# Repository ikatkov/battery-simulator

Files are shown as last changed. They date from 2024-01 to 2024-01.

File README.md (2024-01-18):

# Electronic battery simulator (also works as 35W electronic load)

## Description

Useful for testing battery chargers. 
Designed to use from single lithium batteries to 5S packs i.e. from 3.7V to 18V. Max charging current 2.3A 

Set the "battery" voltage with coarse/fine voltage pots, connect the charger and start the charging process. 
Adjust the "battery" voltage up/down to test how the charger responds. Set max allowed "charge" current with the current pot.

This device simulates battery discharging, current is limited by 200 Ohm resistors i.e. 60-120mA. When in "discharge" mode the
green LED is lit.
When the device simulates battery charging - the current is limited by both the internal charger circuitry and max allowed "charge" current. 
The absolute max is ~2.3A When in "charge" mode the red LED is lit.

A note on `*S` packs:
A typical pack charger senses the voltage across each battery in the pack. This is not implemented inside
but can be built as a pluggable add-on. One side plugs into the banana input of this electronic battery simulator, and the other side forms multiple voltage dividers, as many as the charger wants. Example

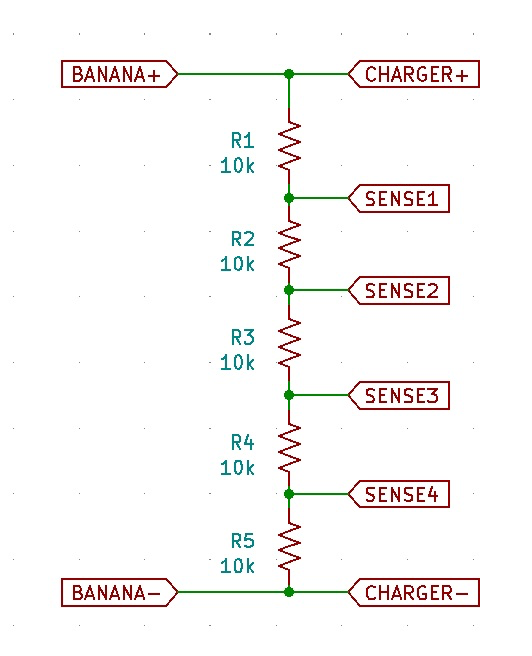
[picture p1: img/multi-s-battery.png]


### Input voltage
Input voltage (VCC): 12-24V. The max "battery" voltage one can set is ~3V below this. 

* LM358 output swing from the top rail is 1.5V
* BJT voltage drop 0.7V
* Diode voltage drop 0.7V

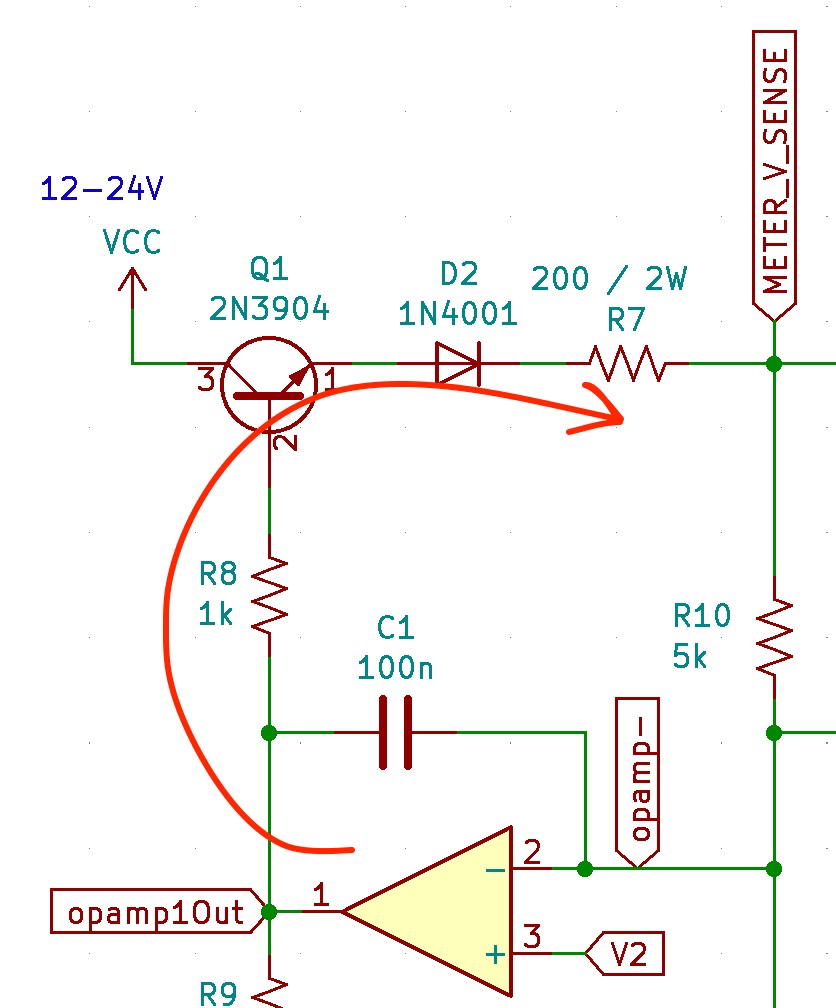
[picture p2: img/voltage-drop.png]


Max voltage available to the cooling fan is ~2.75V below VCC. For the maximum cooling, VCC should be 14V+

* LM358 output swing from the top rail is 1.5V
* LM317 ADJ-to-out is 1.25V

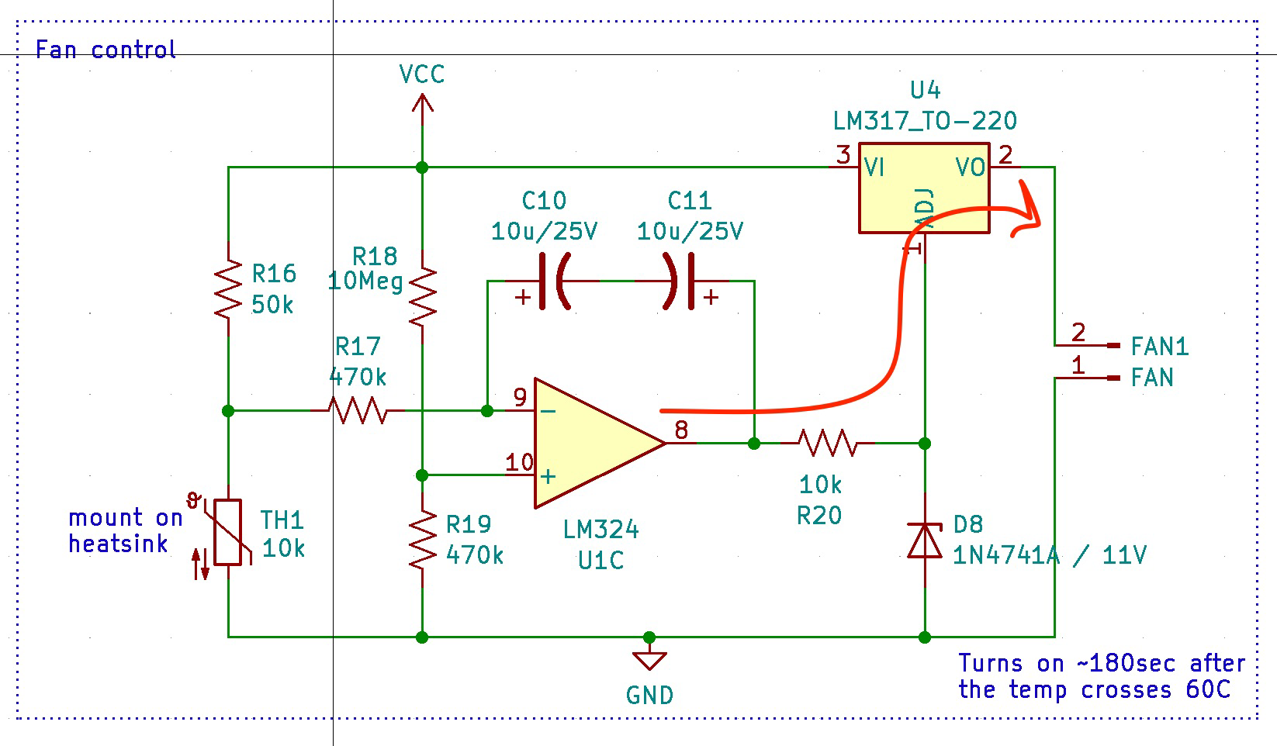
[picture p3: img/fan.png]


### Charger voltage
Charger voltage 0-20V. This is limited by the MOSFET Vds

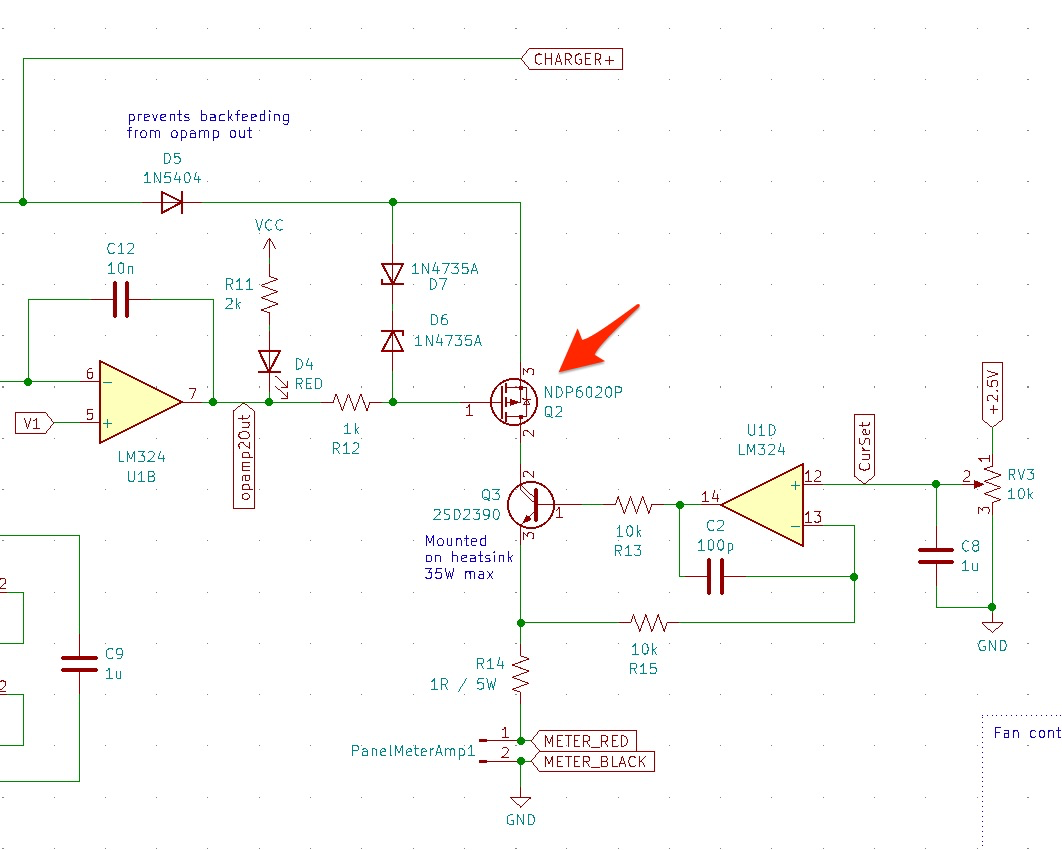
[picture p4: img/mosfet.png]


## Usage

Typical examples:

* manually increase the voltage to 4.2V and expect the lithium battery charger to stop
* manually limit/reduce the max allowed charging current, simulating increased battery resistance, and expect the charger to stop

Non-typical example:

* Set min "battery" voltage, apply external power, and use as a dummy load.

## Limits

Do not exceed 35W continuous heat dissipation. Pass BJT transistor will blow.

Do not exceed 20V charger voltage, switch MOSFET will blow.

Do not exceed 30V input voltage, opamps will blow.

## Fabrication

[LTSpice](ltspice)

[Schematic](schematic.pdf)

[Kicad](kicad)

[Enclosure, knobs](fusion360)

[Notes on fabricating metal enclosures](Metal%20enclosure%20project%20box.md)

Heatsink is not shown on the render below
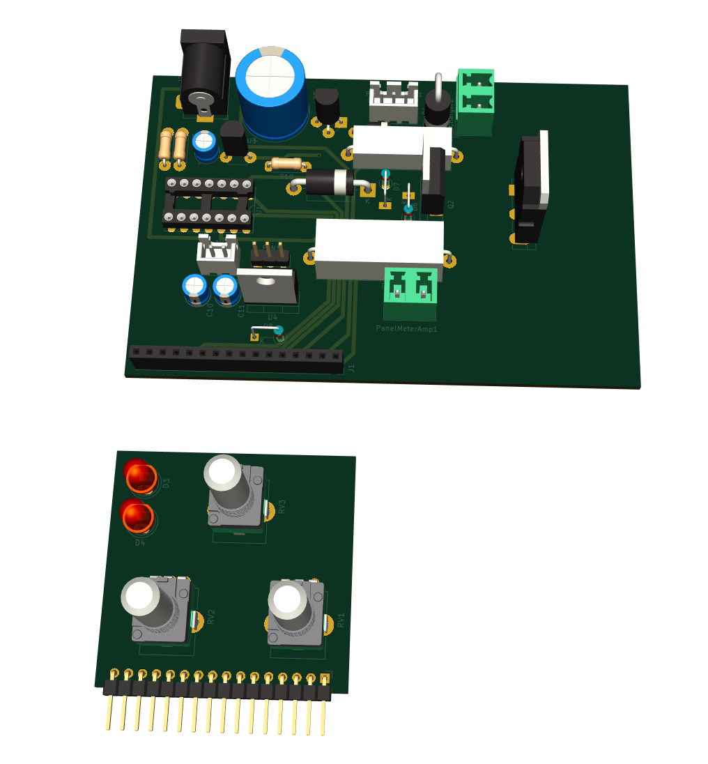
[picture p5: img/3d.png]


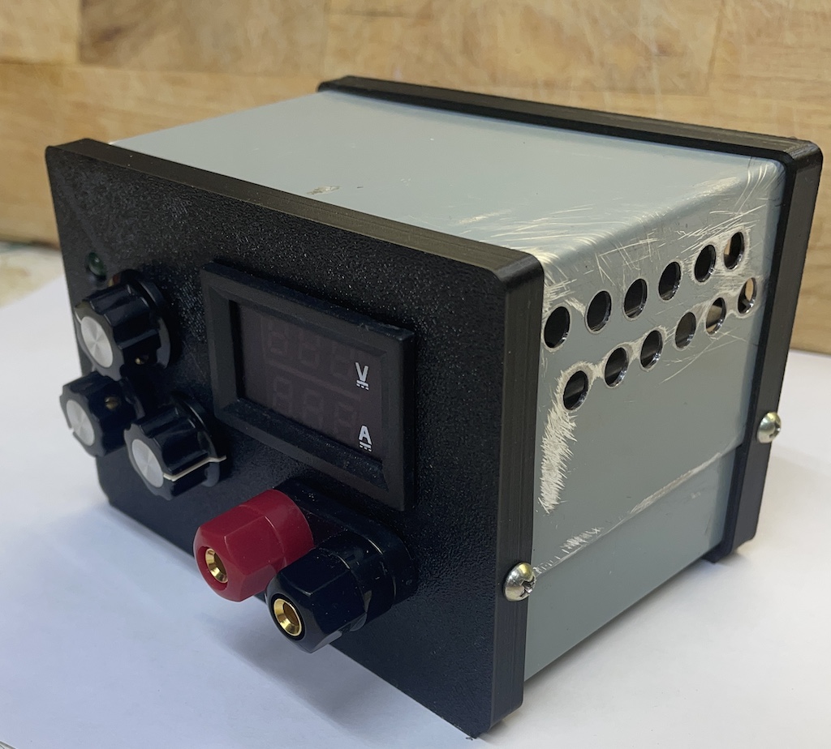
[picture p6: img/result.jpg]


## Notes

The main surprise is that this thing is as usable as a general-purpose dummy load as much as an electronic battery itself.

Do not make daughter boards that have buttons or pots. Mount them separately, and connect them with wires. It is wobbly, the daughter board needs to be secured to a vertical panel, while the vertical panel needs to be removable by design. Total PITA, don't do it again.

Despite PCB being sparsely populated, wires make the inside of the box very very crowded. Need to make the box deeper, +1-2-3 cm depth would not be noticeable but would make wire management easier.

Make the cooling fan blow air on the heat sink along the fins.

This can't be stressed enough - position all connectors, mounting holes and heatsink on the PCB before routing.

See [Notes on fabricating metal enclosures](Metal%20enclosure%20project%20box.md)

For a small enclosure like here, it takes longer to manufacture from metal than to 3D print.

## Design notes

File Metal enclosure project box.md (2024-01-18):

# How to make a project box

1mm thick sheet metal is good enough (rigid enough) for all reasonably sized project boxes.
Harvest from any home appliance that has metal sides. 

Assemble from two metal U-shaped parts. Top and bottom. The top part sides overlap the bottom part sides.
The top and bottom parts are held together by two sheet metal screws on each side.
The front and bottom panels are 3d printed plastic, with all the cutouts. 2mm thickness front, 1.5mm flanges
They overlap metal parts hiding metal cut-off edge imperfections.
Flanges are slotted to hold plastic better

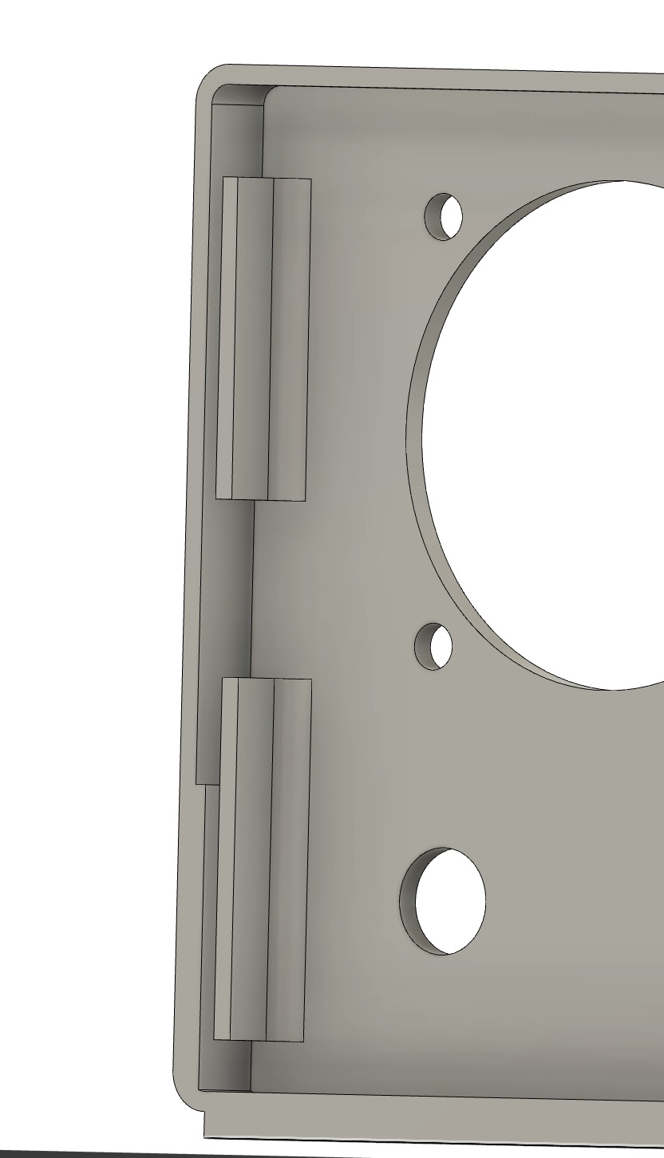
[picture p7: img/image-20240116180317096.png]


Notice how sheet metal parts fit into the gaps. Notice different set-back at the top and bottom due to sheet metal overlap

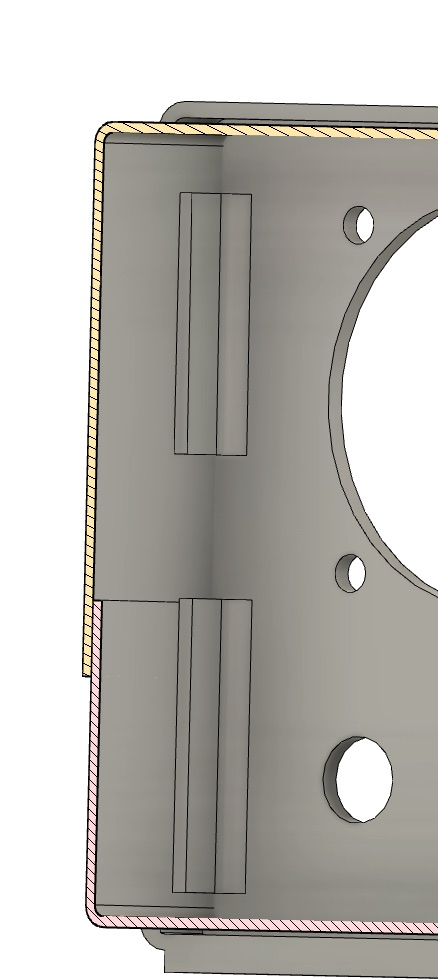
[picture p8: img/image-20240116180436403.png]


Use a sheet metal screw with a pilot hole to hold it together. Drill the hole once the box is fully assembled, right through 
plastic-metal-metal-plastic.

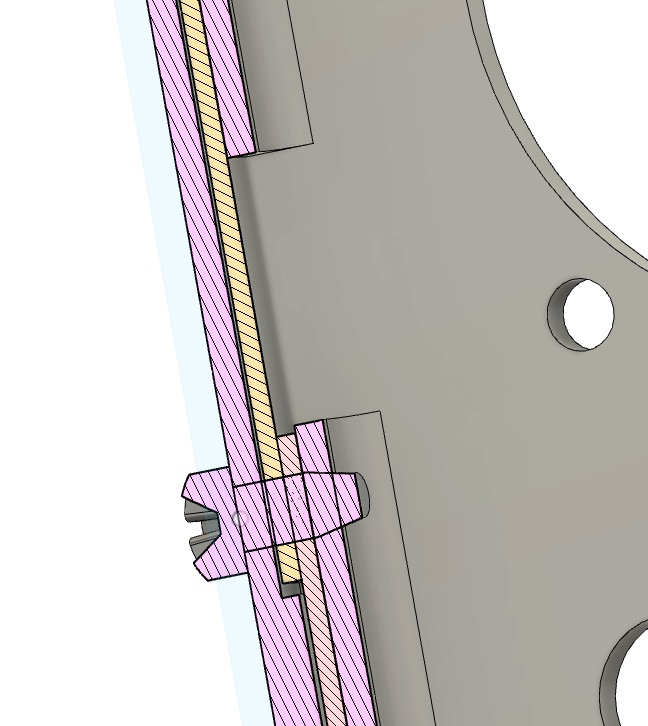
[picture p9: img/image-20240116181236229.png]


# Result



## Metal cutting tips
Align unfolded U-shaped parts together, in one long pattern. So that once it is cut, their width is the same. This width is the depth of the box. 
The best way of cutting a straight line is to score hard and then bend/unbend until the metal breaks.
Handholding power sheers gives OK results. Depends on a steady hand and might be a 1mm deviation at best. Need to try to use a metal plate as a guide. It seems tricky, as the shear nose is round.

## Metal bending tips
When bending, align the bend line with the gap between hand brake plates. Move the top metal plate ~0.2-0.3mm away from the crack. Maybe use these printed dotted lines on the pattern, to know how much to move back?

## PCB mounting tips
Place PCB in the desired location, and mark holes on the bottom metal part with a marker. Drill. 
Expect the result to be off the holes in the PCB. Enlarge PCB holes to align the metal holes with a rotary tool.
Take a 6mm spacer with threads inside, and screw the PCB from the top to it, now PCB has tiny "legs". Use a short screw to leave 50% of the spacer empty on the inside. Use another short screw from the bottom of the box, to mount the whole PCB assembly through these legs. Two machine screws are facing each other.

Do a proper ribbon/wire connection from the main horizontal PCB to panel mounted vertical one, do not do pins and headers - the vertical board becomes wobbly. This is especially bad if the vertical board has potentiometers or buttons.

## PCB layout tips
Set back mounting holes 15mm away from edges, otherwise front/back plastic panel flanges conflict with bolt heads. Expect the holes to be enlarged manually later.
Leave enough space around ~ 10mm diameter restriction zone.

Position heatsinks and fans and ports/connectors before doing any trace routing. Make the fan blow air on them.

## Industry examples

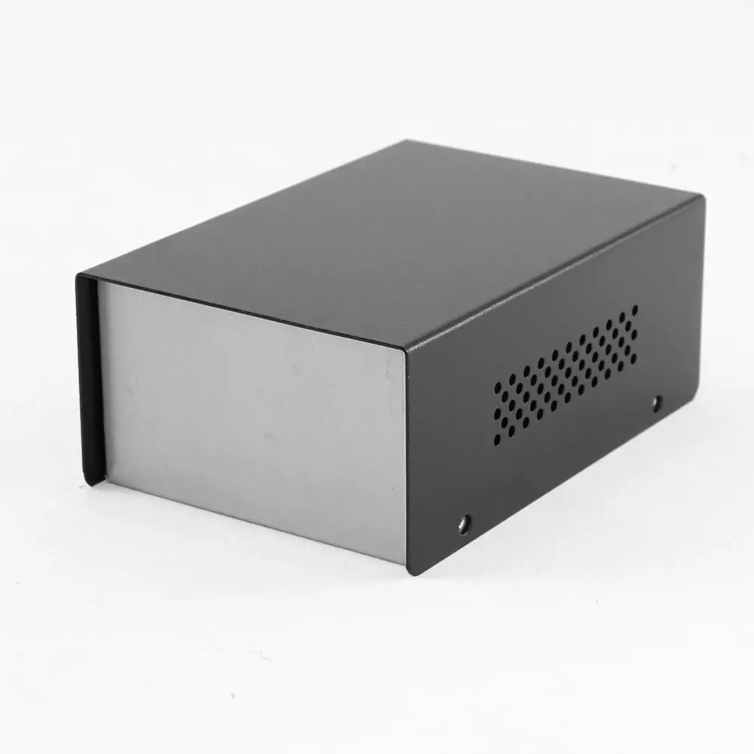
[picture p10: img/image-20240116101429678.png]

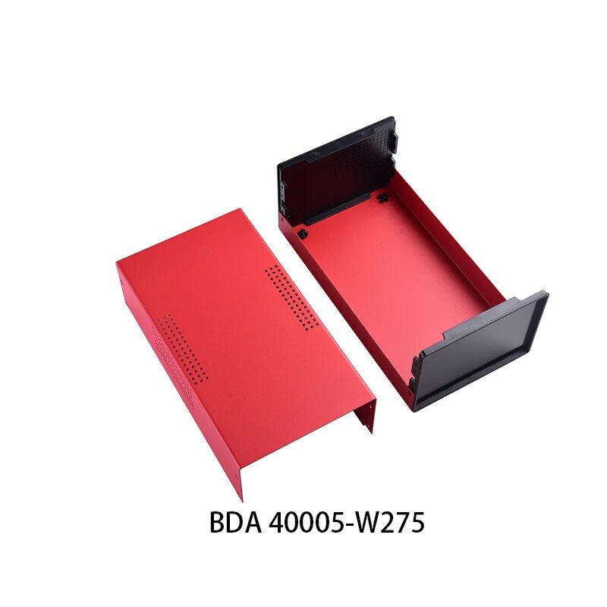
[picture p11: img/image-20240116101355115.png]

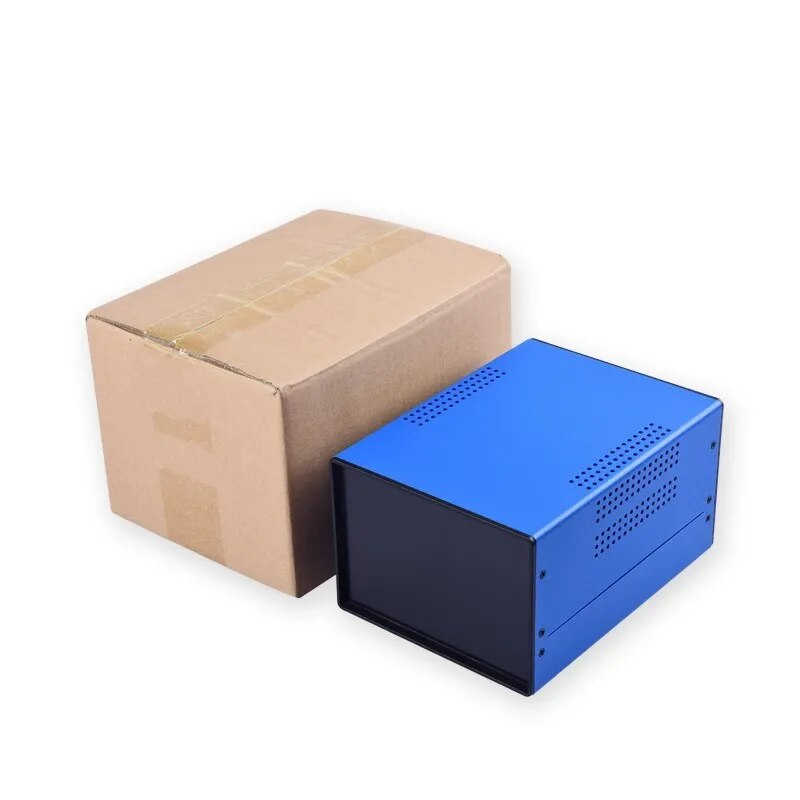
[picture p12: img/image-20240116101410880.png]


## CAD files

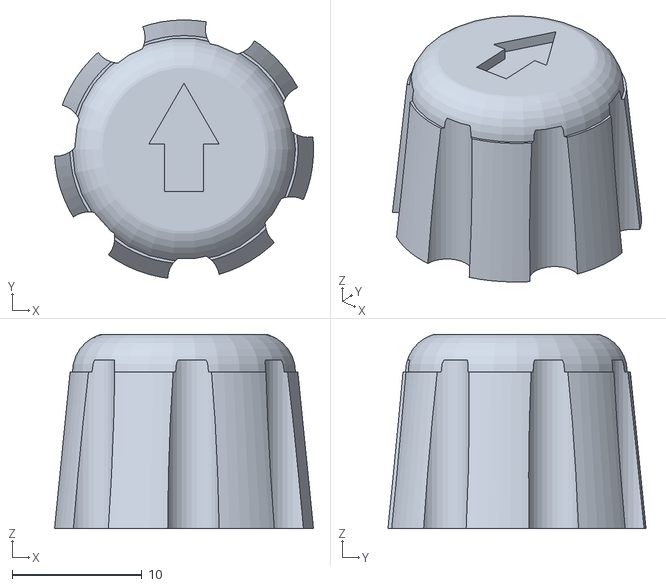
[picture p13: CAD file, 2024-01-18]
fusion360/knob.stl
20.0 x 19.9 x 15.0

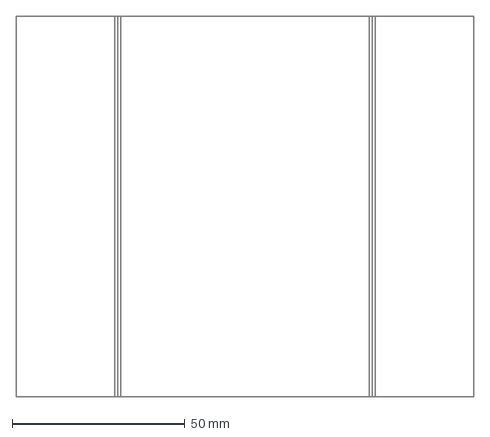
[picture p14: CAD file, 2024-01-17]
kicad/sheet-metal-bottom-dxf.dxf
132.2 x 110.0 mm

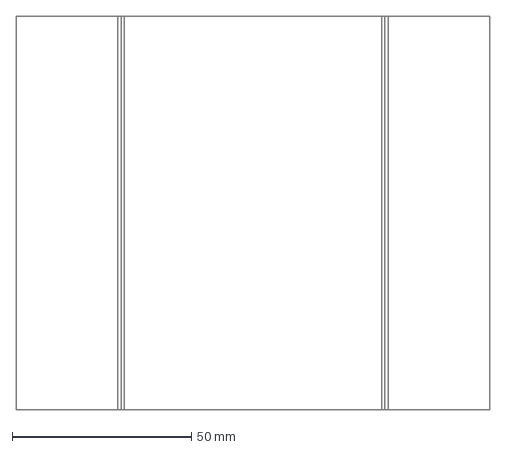
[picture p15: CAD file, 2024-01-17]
kicad/sheet-metal-bottom.dxf
132.2 x 110.0 mm

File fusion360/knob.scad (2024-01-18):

/*
Knob Factory

Version 1.2

© 2012 Steve Cooley    ( http://sc-fa.com , http://beatseqr.com , http://hapticsynapses.com )
© 2021 Matthias Ansorg ( https://ma.juii.net )

Description
===========
A parametric OpenSCAD design that allows to generate all kinds of knobs. Examples: small knobs for potentiometer inputs; 
knobs for turning the extruder or an axis of the 3D printer manually; water spout knobs etc.. It's a good idea to print 
only the lower 5 mm at first and then abort the print, to test if the hole diamater fits well on the shaft or if the measures 
have to be tuned further.

Licence
=======
Knob Factory is licensed under a Creative Commons Attribution 3.0 Unported License according to 
the licence note found at https://www.thingiverse.com/thing:20513 . Based on a work at sc-fa.com. 
Permissions beyond the scope of this license may be available at http://sc-fa.com/blog/contact .
You can view the terms of the license here: http://creativecommons.org/licenses/by/3.0/

Version History
===============
1.2  2021-01-03  Option to generate knobs with stems. Major refactorings. Republished as remix on Thingiverse.
1.1  2012-04-12  Fixed the arrow indicator code to be more robust and easier to adjust parameters for.
1.0  2012-03-??  Initial release at https://www.thingiverse.com/thing:20513 .

Open Tasks
==========
* @todo Adjust $fn based on the quality parameter so that if ≥30 faces on the circumference are specified, the shape 
    will be made "round", using the current quality setting.
* @todo Change the assembly order so that the external indicator is not cut by the cone indents even if they cut to the very bottom.
* @todo Add a horizontal cylinder around the setscrew hole, providing sufficient thread length where thin stems walls don't.
* @todo Add support for melt-in nuts that can be used for the setscrew hole, as seen at https://www.thingiverse.com/thing:3475324
* @todo Provide an option to chamfer rather than round along the top, to allow printing without support when flipped over.
* @todo Refactor the top_rounding() module.
* @todo Make the top_rounding() operation faster. Everything else is already fast enough to navigate fluently in preview mode.
* @todo Add a printer_hole_scale parameter (or similar) to scale holes so that printing them offsets any printer calibration 
    error. This keeps local calibration issues separate form the shafthole_radius parameter, which is good for sharing configurations.
* @todo Add support for more shaft shapes (rectangular, gear shaped etc.).
* @todo Support knurling of the knob circumference.
* @todo Add support for cutouts that leave spokes between the hub and circumference.
* @todo Some more "@todo" items as available inside the source code.
* @todo Add a mode where the sphere and cone indents can be rendered, to get an idea how to adapt them if they do not cut anything.
*/


// (1) CUSTOMIZER PARAMETERS
// ======================================================================

/* [Basic Parameters] */
// ---------------------

// Degree of detail in the output to allow faster previews. Influences segments for a full circle. NOT IMPLEMENTED YET.
quality = "final rendering"; // ["fast preview", "preview", "rendering", "final rendering"]

// Top radius of the main (cylindrical or conical) shape. [mm]
knob_radius_top = 8.5;

// Bottom radius of the main (cylindrical or conical) shape. [mm]
knob_radius_bottom = 10;

// Height of the main (cylindrical or conical) knob shape, without the stem. [mm]
knob_height = 15;

// Number of faces on the circumference of the knob, as on a regular polygon. ≥30 means "round, using current quality setting".
knob_faces = 70;

// Radius (at the widest point) of the shaft to which the knob is mounted. [mm]
shafthole_radius = 3.25;

// Depth of the hole for the shaft. If the knob is stopped by something mounted to the shaft, you can be generous with this measure, allowing it to catch debris from mounting without stopping the knob before its final position. [mm]
shafthole_height = 12;

// Number of faces on the cylindrical edge of the shaft hole, allowing to create holes for square, hexagonal etc. shafts. ≥30 means "round, using current quality setting".
shafthole_faces = 10;

// How much to cut off to create a D-shaped shafthole cross-section. 0 to keep it round. [mm]
shafthole_cutoff_arc_height = 0;


/* [Stem (optional)] */
// --------------------

// Whether to place the knob on a stem to form a mushroom shape.
enable_stem = false;

// Radius of the stem. [mm]
stem_radius = 5;

// Height of the stem. [mm]
stem_height = 6;

// Number of faces on the cylindrical part of the stem. ≥30 means "round, using current quality setting".
stem_faces = 30;

// Height of the section where the stem radius adapts, as part of the stem height. [mm]
stem_transition_height = 5;

// Radius to which the stem radius adapts at the top of the stem. [mm]
stem_transition_radius = 5;


/* [Stem _cutoff (optional)] */
// --------------------

// Whether to make a cut off for stem 
enable_stem_cutoff = false;

// Radius of the stem. [mm]
stem_cutoff_radius = 6.5;

// Height of the stem. [mm]
stem_cutoff_height = 7;

// Number of faces on the cylindrical part of the stem. ≥30 means "round, using current quality setting".
stem_cutoff_faces = 30;

// Height of the section where the stem radius adapts, as part of the stem height. [mm]
stem_cutoff_transition_height = 5;

// Radius to which the stem radius adapts at the top of the stem. [mm]
stem_cutoff_transition_radius = 5;


/* [Setscrew Hole (optional)] */
// -------------------------

// Create a hole for a set screw, as required by some potentiometer or motor shafts to have their knobs affixed.
enable_setscrew_hole = false;

// Radius of the set screw hole. [mm]
setscrew_hole_radius = 1.01;

// Height of the set screw hole's center over the base of the knob. [mm]
setscrew_hole_height = 4;

// Number of faces on the cylindrical edge of the set screw hole. ≥30 means "round, using current quality setting".
setscrew_hole_faces = 20;


/* [Top Rounding (optional)] */
// ---------------------------------

// Enable rounding of the top edge. (Other "top rounding *" parameters are only relevant if checked.)
enable_top_rounding = true;

// Radius to use for rounding teh top edge. [mm]
top_rounding_radius = 3;

// Cylinder faces to use for the cylinder having the rounded top edge. ≥30 means "round, using current quality setting".
top_rounding_faces = 30;


/* [Engraved Indicator (optional)] */
// -------------------------------

// Whether to create an engraved indicator arrow on the top surface, or not.
enable_engraved_indicator = true;

// Scale factor for the overall arrow size.
engraved_indicator_scale = 1;

// Scale factor for the arrow's head size.
engraved_indicator_head_scale = 1.3;

// Scale factor for the arrow's shaft size.
engraved_indicator_shaft_scale = 1;

// How much to move the arrow into its pointing direction. Positive or negative. [mm]
engraved_indicator_move_forward = 2;

// Engraving depth. [mm]
engraved_indicator_depth = 3;


/* [External Indicator (optional)] */
// ------------------------------

// Whether to create a dial, protruding from the bottom of the knob's circumference.
enable_external_indicator = false;

// Height of the dialhand, from the bottom of the knob body. [mm]
external_indicator_height = 4;

// Length of the dialhand protruding over the bottom radius of the knob main shape. [mm]
external_indicator_length = 2;


/* [Sphere Indents (optional)] */
// --------------------------------------

// Whether to create cutouts around the top edge or circumference using spheres (or rather regular polyhedra) arranged in a circle.
enable_sphere_indents = false;

// Number of indenting spheres.
sphere_indents_count = 13;

// Radius of the indenting spheres. [mm]
sphere_indents_radius = 4;

// Number of faces around the outer circumference of the indenting spheres. ≥30 means "round, using current quality setting".
sphere_indents_faces = 20;

// Distance of the indenting spheres' centers from the centerline of the knob. [mm]
sphere_indents_center_distance = 16;

// Maximum depth cut by the indenting spheres, measured from the top surface of the knob. [mm]
sphere_indents_cutdepth = 2;

// Rotation offset of all spheres. Allows to align the indentations with the indicator, setscrew or outer faces. [degrees]
sphere_indents_offset_angle = 35;


/* [Cone Indents (optional)] */
// ------------------------------------

// Whether to create cutouts around the top edge or circumference using cones or cylinders arranged in a circle. When using many narrow cylinders you can create a serrating effect for better grip on the circumference surface.
enable_cone_indents = true;

// Number of indenting cones.
cone_indents_count = 7;

// Number of faces around the outer circumference of the indenting cones. ≥30 means "round, using current quality setting".
cone_indents_faces = 30;
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

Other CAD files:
fusion360/assembly.f3z

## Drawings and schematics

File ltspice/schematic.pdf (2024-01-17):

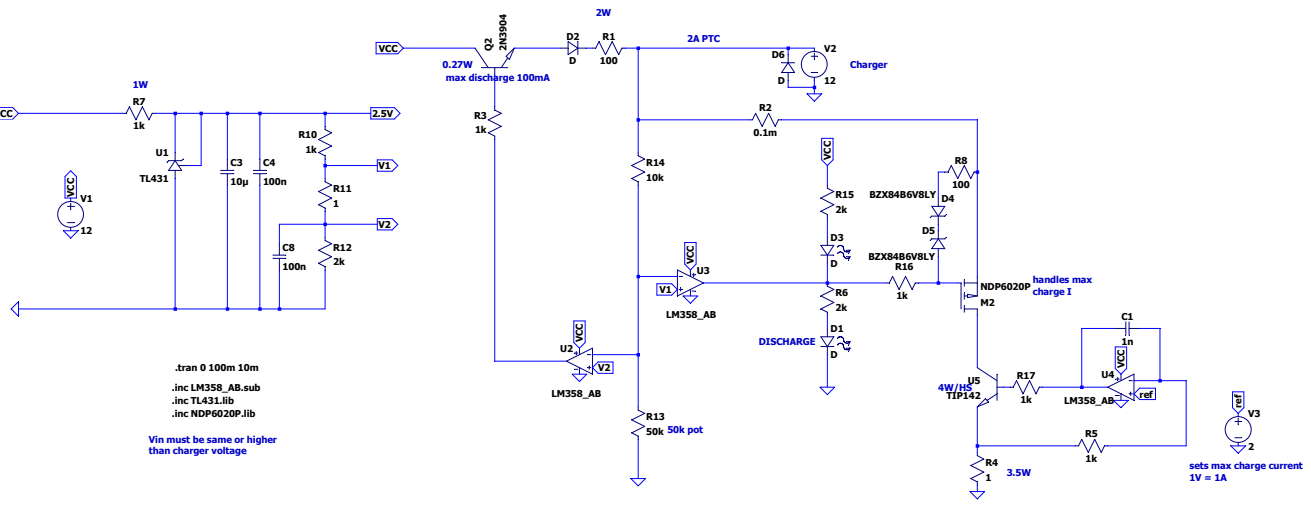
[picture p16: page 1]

Vin must be same or higher
than charger voltage

sets max charge current

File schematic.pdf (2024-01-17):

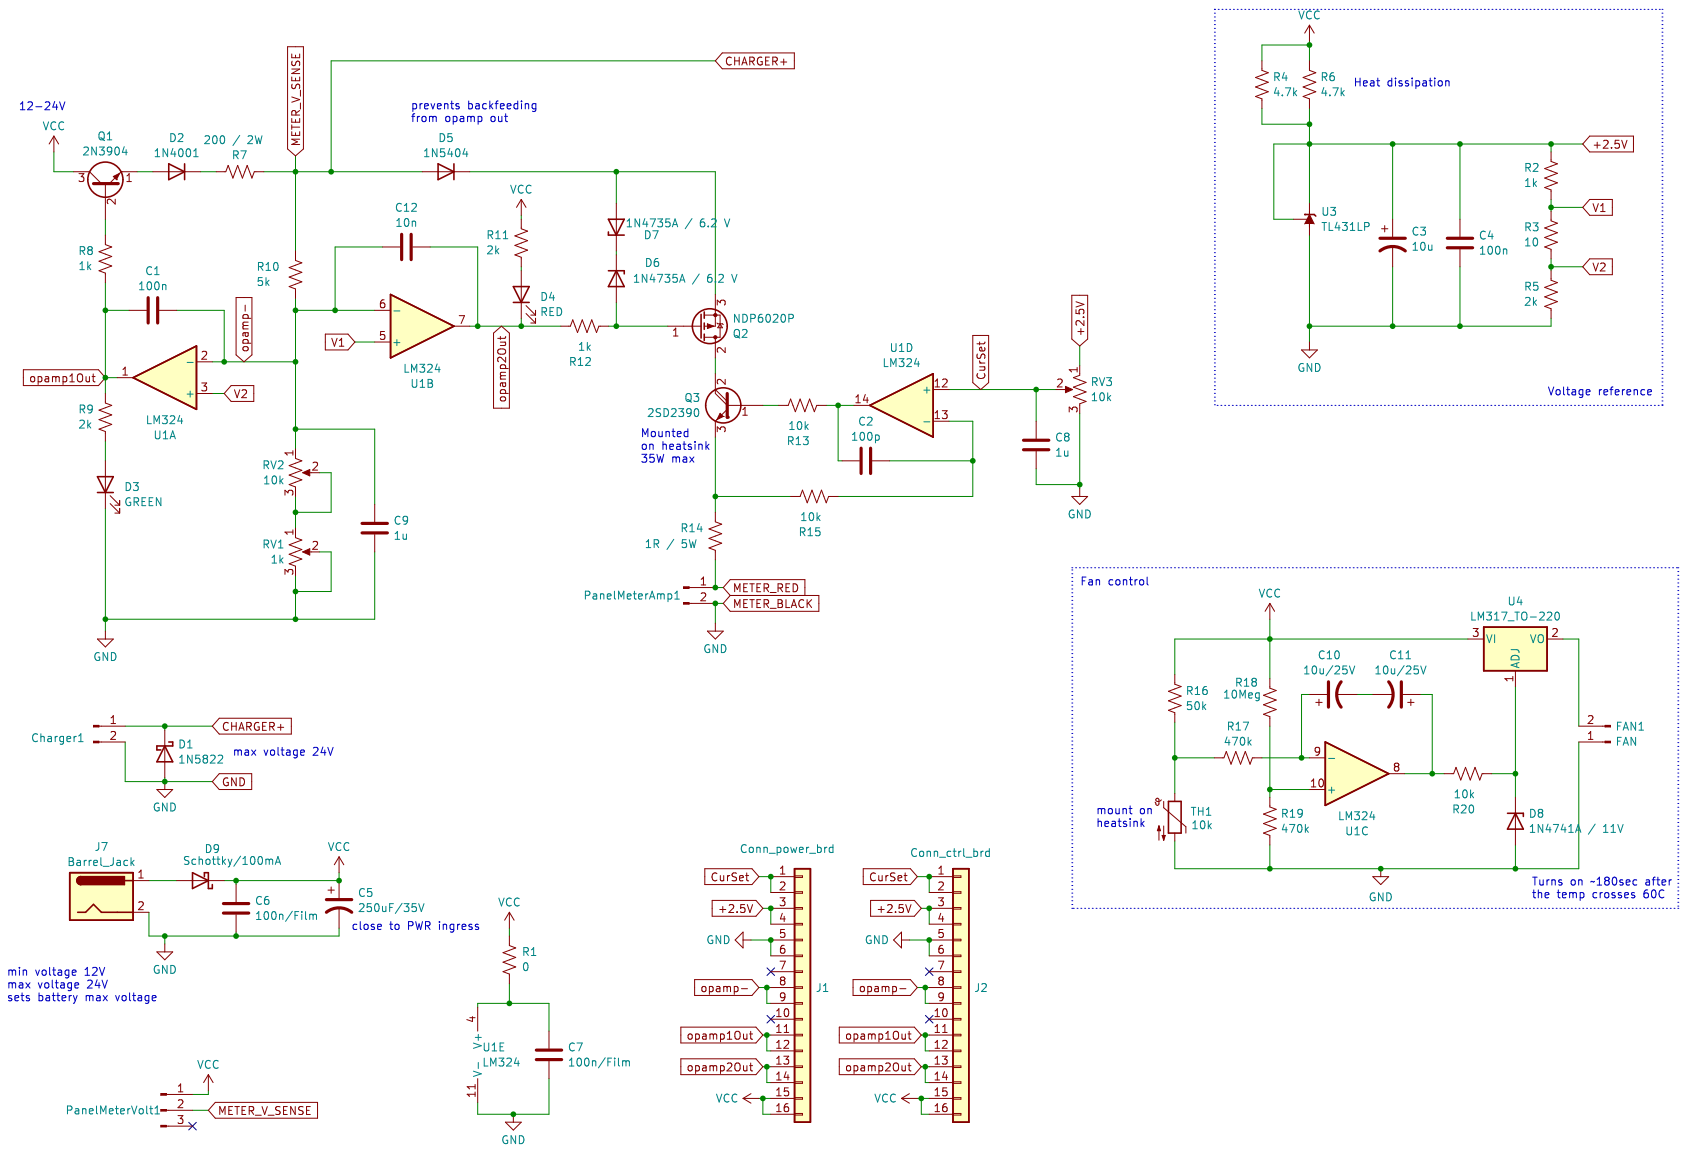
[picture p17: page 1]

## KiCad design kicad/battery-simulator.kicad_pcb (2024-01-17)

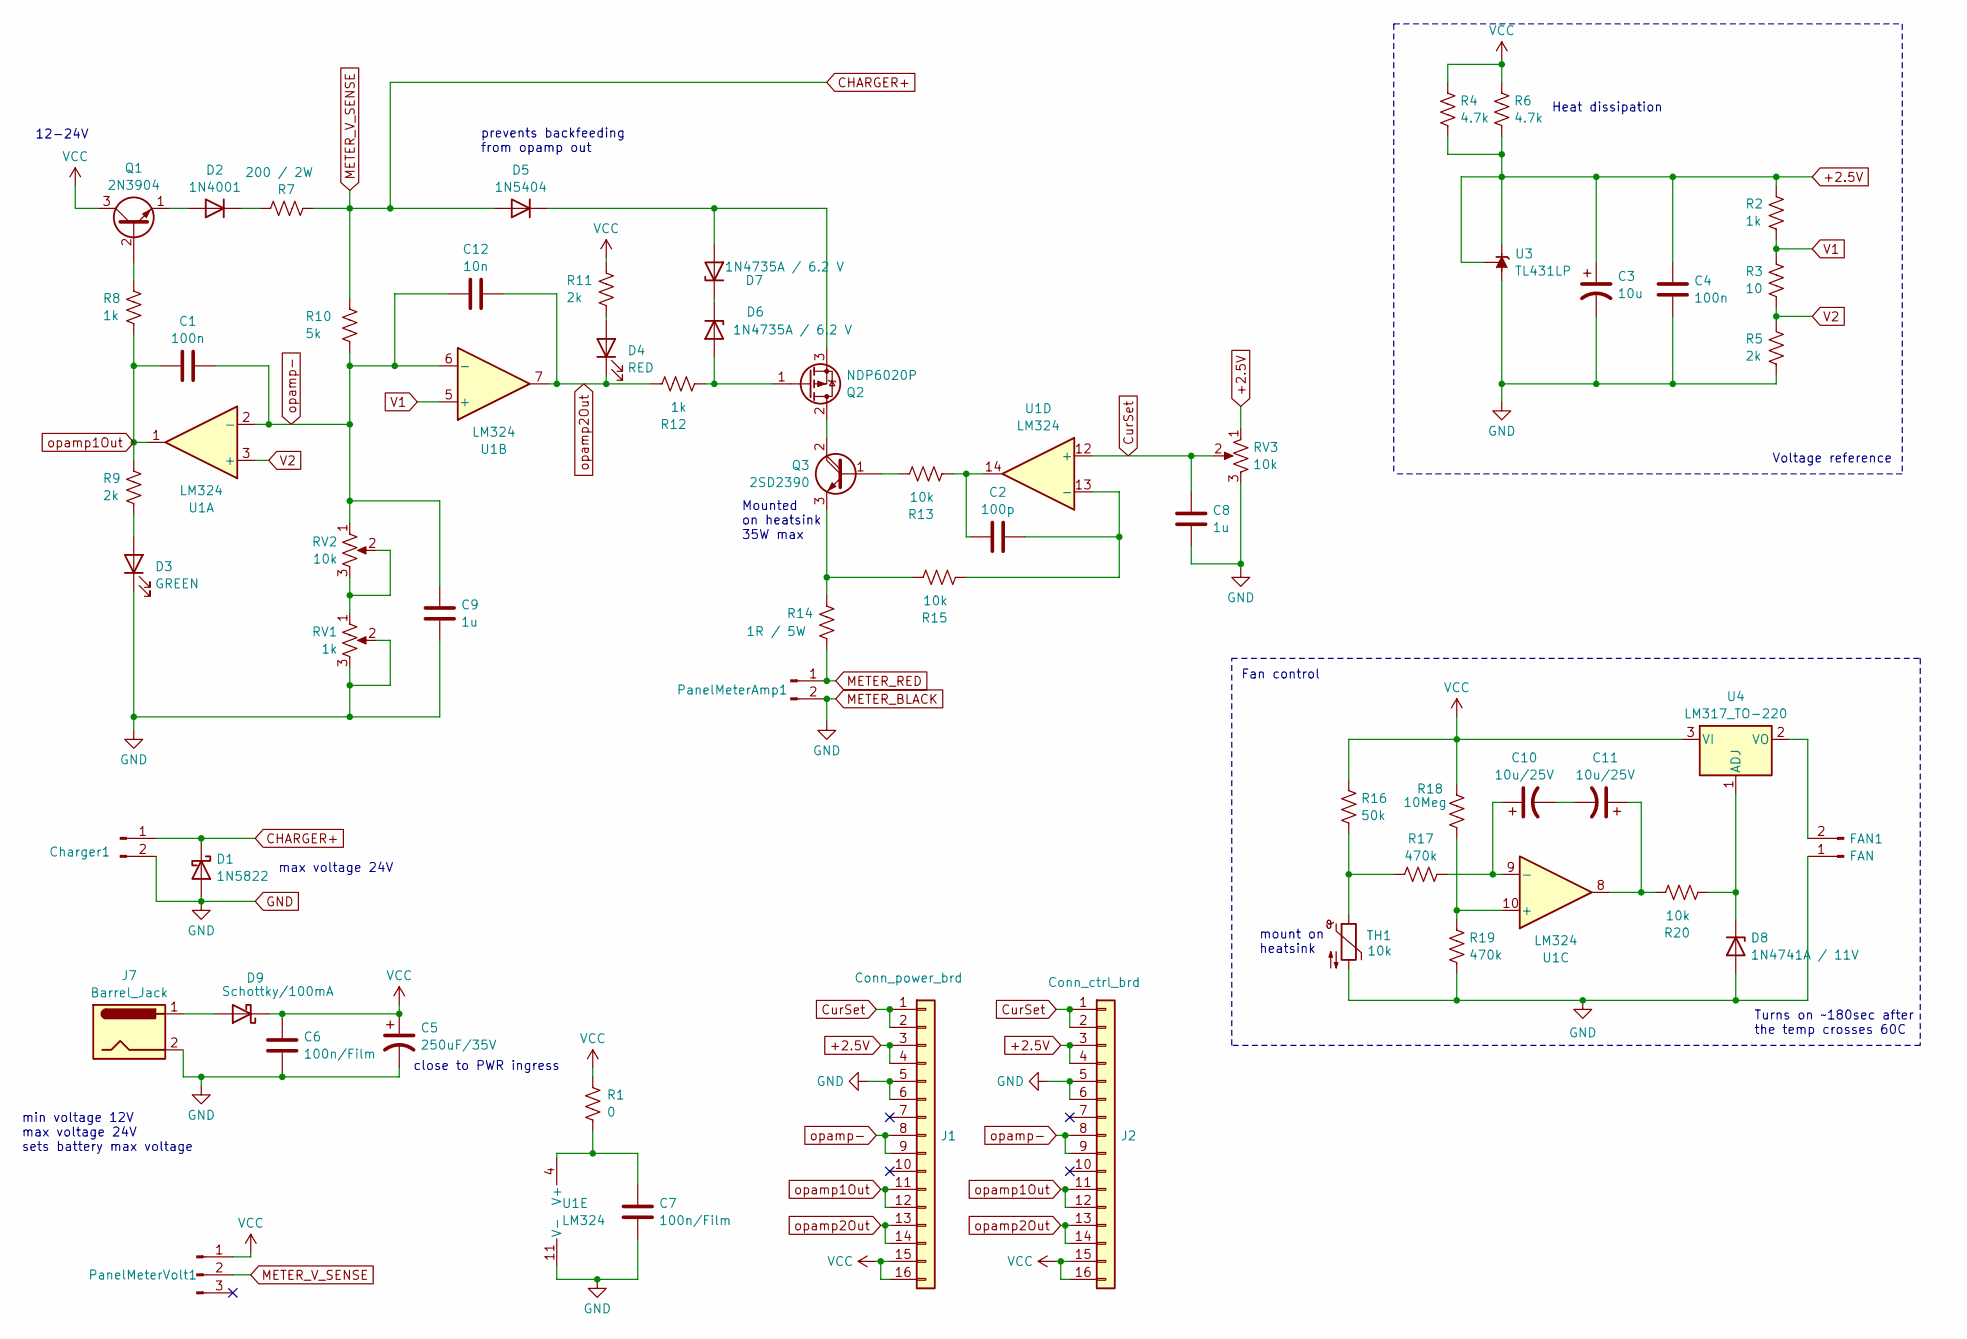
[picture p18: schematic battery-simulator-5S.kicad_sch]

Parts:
C1, C4: 100n; C_1206_3216Metric
C2: 100p; C_1206_3216Metric
C3: 10u; CP_Radial_D5.0mm_P2.50mm
C5: 250uF/35V; CP_Radial_D14.0mm_P5.00mm
C6, C7: 100n/Film; C_1206_3216Metric
C8, C9: 1u; C_1206_3216Metric
C10, C11: 10u/25V; CP_Radial_D5.0mm_P2.50mm
C12: 10n; C_1206_3216Metric
Charger1: Charger; PhoenixContact_MCV_1,5_2-G-5.08_1x02_P5.08mm_Vertical
D1: 1N5822; D_DO-201AD_P5.08mm_Vertical_AnodeUp
D2: 1N4001; D_DO-41_SOD81_P10.16mm_Horizontal
D3: GREEN; LED_D5.0mm
D4: RED; LED_D5.0mm
D5: 1N5404; D_DO-201AD_P15.24mm_Horizontal
D6, D7: 1N4735A / 6.2 V; D_DO-35_SOD27_P5.08mm_Vertical_KathodeUp
D8: 1N4741A / 11V; D_DO-35_SOD27_P5.08mm_Vertical_KathodeUp
D9: Schottky/100mA; D_SMA
FAN1: FAN; PinHeader_1x03_P2.54mm_Vertical
J1: Conn_power_brd; PinSocket_1x16_P2.54mm_Vertical
J2: Conn_ctrl_brd; PinHeader_1x16_P2.54mm_Horizontal
J7: Barrel_Jack; BarrelJack_Horizontal
PanelMeterAmp1: Panel Meter Amp; PhoenixContact_MCV_1,5_2-G-5.08_1x02_P5.08mm_Vertical
PanelMeterVolt1: Panel Meter Volt; JST_XH_B3B-XH-A_1x03_P2.50mm_Vertical
Q1: 2N3904; TO-92L_Wide
Q2: NDP6020P; TO-220-3_Vertical
Q3: 2SD2390; TO-3P-3_Vertical
R1: 0; R_1206_3216Metric
R2, R8, R12: 1k; R_0805_2012Metric
R3: 10; R_0805_2012Metric
R4, R6: 4.7k; R_Axial_DIN0207_L6.3mm_D2.5mm_P7.62mm_Horizontal
R5, R9, R11: 2k; R_0805_2012Metric
R7: 200 / 2W; R_Axial_Power_L20.0mm_W6.4mm_P22.40mm
R10: 5k; R_Axial_DIN0207_L6.3mm_D2.5mm_P7.62mm_Horizontal
R13, R15, R20: 10k; R_0805_2012Metric
R14: 1R / 5W; R_Axial_Power_L25.0mm_W9.0mm_P27.94mm
R16: 50k; R_0805_2012Metric
R17: 470k; R_1206_3216Metric
R18: 10Meg; R_0805_2012Metric
R19: 470k; R_0805_2012Metric
RV1: 1k; Potentiometer_Bourns_PTV09A-1_Single_Vertical
RV2, RV3: 10k; Potentiometer_Bourns_PTV09A-1_Single_Vertical
TH1: 10k; JST_XH_B2B-XH-A_1x02_P2.50mm_Vertical
U1: LM324; DIP-14_W7.62mm_Socket
U3: TL431LP; TO-92L_Wide
U4: LM317_TO-220; TO-220-3_Vertical

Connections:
+2.5V: C3.1, C4.2, J1.3, J1.4, J2.3, J2.4, R2.1, R4.2, R6.2, RV3.1, U3.1 (REF), U3.3 (K)
CHARGER+: Charger1.1, D1.1 (K), D5.2 (A), PanelMeterVolt1.2, R7.2, R10.1
CurSet: C8.2, J1.1, J1.2, J2.1, J2.2, RV3.2, U1.12 (+)
GND: C3.2, C4.1, C5.2, C6.1, C7.1, C8.1, C9.1, Charger1.2, D1.2 (A), D3.1 (K), D8.2 (A), FAN1.1, J1.5, J1.6, J2.5, J2.6, J7.2, PanelMeterAmp1.2, R5.2, R19.2, RV1.2, RV1.3, RV3.3, TH1.2, U1.11 (V-), U3.2 (A)
METER_RED: PanelMeterAmp1.1, R14.2
unnamed: C2.2, R13.2, U1.14
unnamed: C10.2, C11.2
unnamed: C11.1, R20.1, U1.8
unnamed: D2.2 (A), Q1.1 (E)
unnamed: D2.1 (K), R7.1
unnamed: D3.2 (A), R9.2
unnamed: D4.2 (A), R11.2
unnamed: D5.1 (K), D7.2 (A), Q2.3 (S)
unnamed: D6.2 (A), Q2.1 (G), R12.2
unnamed: D6.1 (K), D7.1 (K)
unnamed: D8.1 (K), R20.2, U4.1 (ADJ)
unnamed: D9.2 (A), J7.1
unnamed: FAN1.2, U4.2 (VO)
unnamed: Q1.2 (B), R8.1
unnamed: Q2.2 (D), Q3.2 (C)
unnamed: Q3.1 (B), R13.1
unnamed: Q3.3 (E), R14.1, R15.1
unnamed: R16.2, R17.1, TH1.1
unnamed: RV1.1, RV2.2, RV2.3
unnamed: R18.2, R19.1, U1.10 (+)
unnamed: C10.1, R17.2, U1.9 (-)
unnamed: C2.1, R15.2, U1.13 (-)
unnamed: C7.2, R1.2, U1.4 (V+)
V1: R2.2, R3.1, U1.5 (+)
V2: R3.2, R5.1, U1.3 (+)
VCC: C5.1, C6.2, D9.1 (K), J1.15, J1.16, J2.15, J2.16, PanelMeterVolt1.1, Q1.3 (C), R1.1, R4.1, R6.1, R11.1, R16.1, R18.1, U4.3 (VI)
opamp1Out: C1.2, J1.11, J1.12, J2.11, J2.12, R8.2, R9.1, U1.1
opamp2Out: C12.1, D4.1 (K), J1.13, J1.14, J2.13, J2.14, R12.1, U1.7
opamp-: C1.1, C9.2, C12.2, J1.8, J1.9, J2.8, J2.9, R10.2, RV2.1, U1.2 (-), U1.6 (-)

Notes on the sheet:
min voltage 12V max voltage 24V sets battery max voltage
close to PWR ingress
mount on heatsink
Voltage reference
max voltage 24V
Mounted on heatsink 35W max
Turns on ~180sec after the temp crosses 60C
prevents backfeeding from opamp out
12-24V
Fan control
Heat dissipation

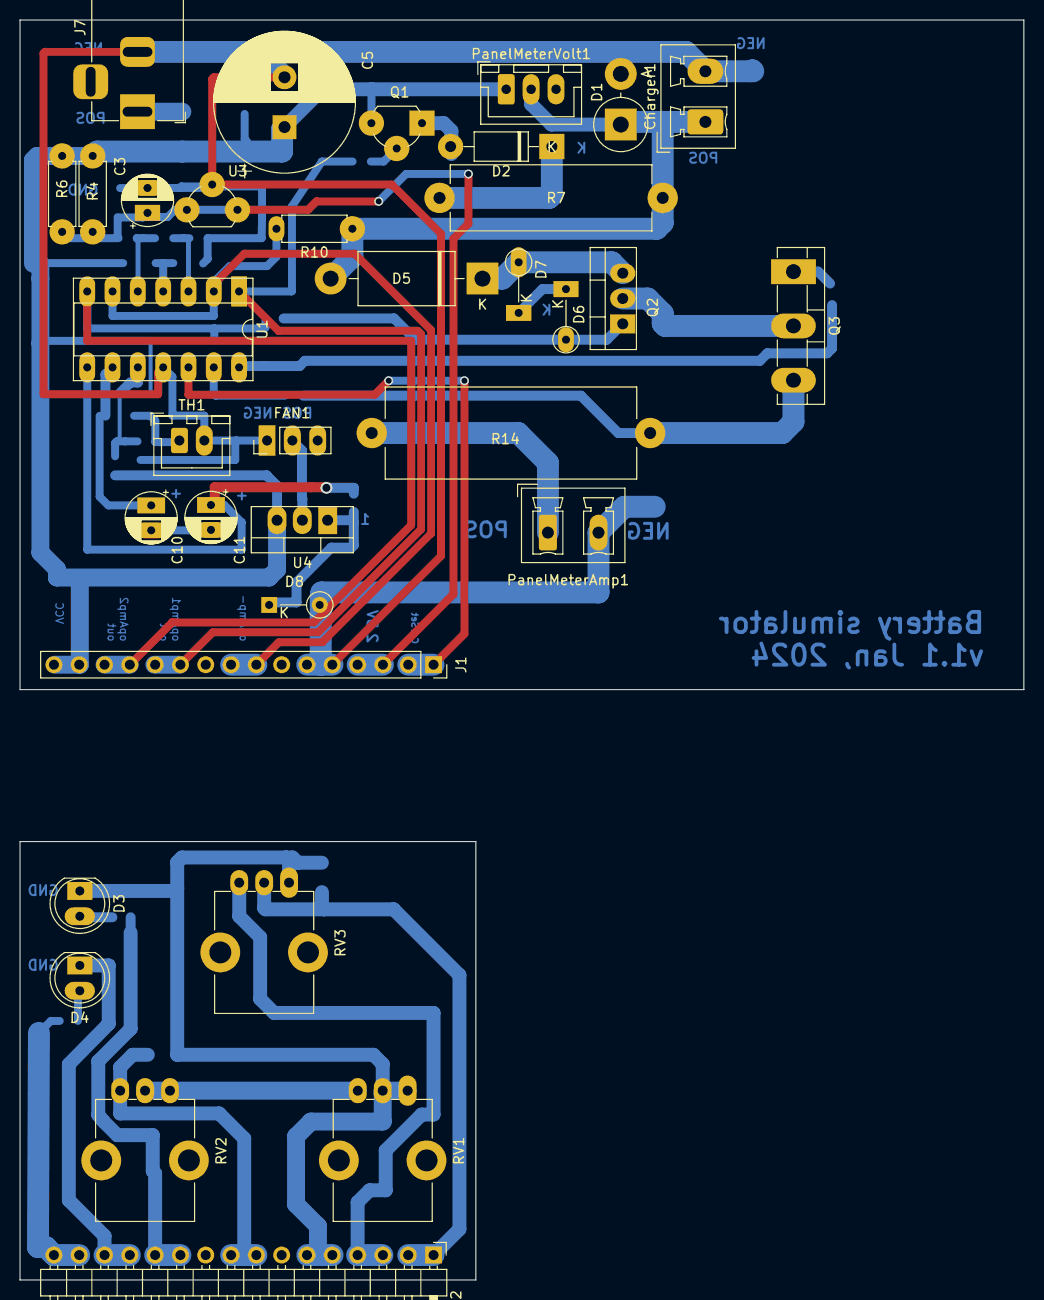
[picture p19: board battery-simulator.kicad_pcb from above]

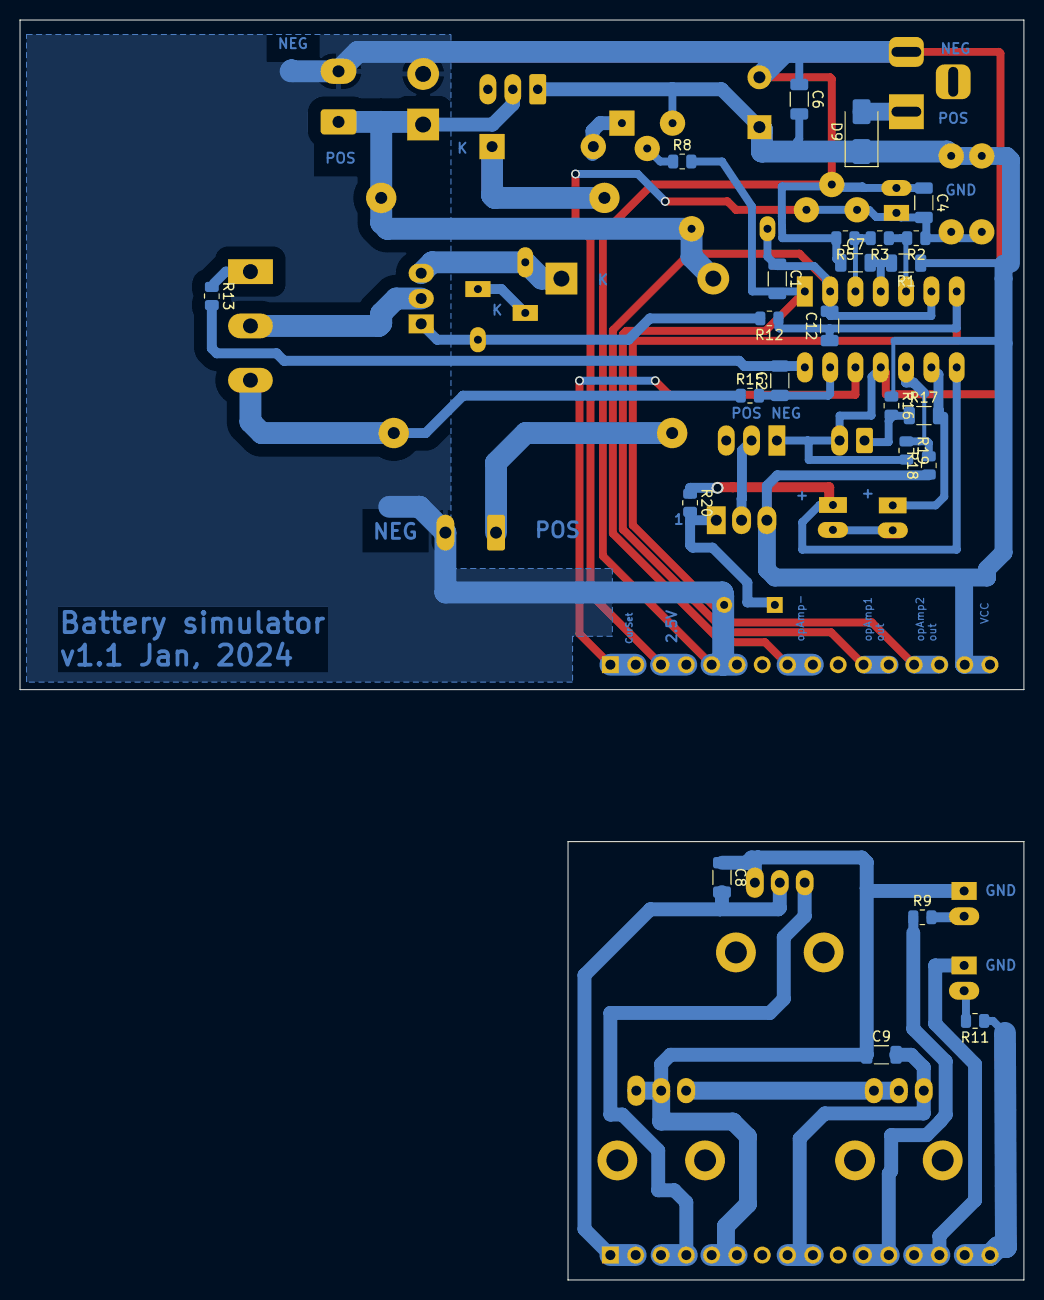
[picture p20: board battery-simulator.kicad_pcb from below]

Board: 4 copper layers, 100.8 x 67.2 mm, 58 parts (24 on the bottom side), 34 nets.

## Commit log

2024-01-17 More ideas
    [battery-simulator-5S.kicad_sch]
2024-01-18 add knobs models
    [knob.scad, knob.stl]
